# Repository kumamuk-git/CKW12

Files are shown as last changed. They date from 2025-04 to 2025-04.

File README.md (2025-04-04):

# CKW12
CKW12はクリックあり1U水平ロータリエンコーダです  
+ EC12に極力寄せたフットプリント
+ 通常プロファイル、ロープロファイルいずれの高さにも調整可能

## Whare to Buy

[BOOTH](https://kumamuk.booth.pm/items/6771437)にて組み立てキットが購入可能

## Build Guide

ビルドガイドは[こちら](https://github.com/kumamuk-git/CKW12/blob/main/doc/buildguide.md)

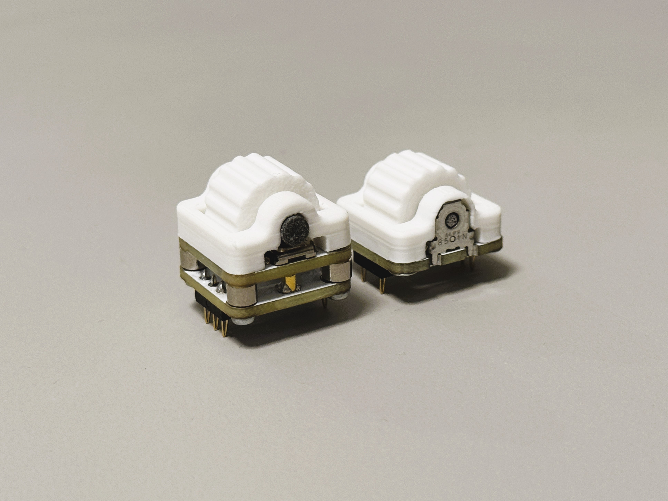
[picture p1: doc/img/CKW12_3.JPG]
  
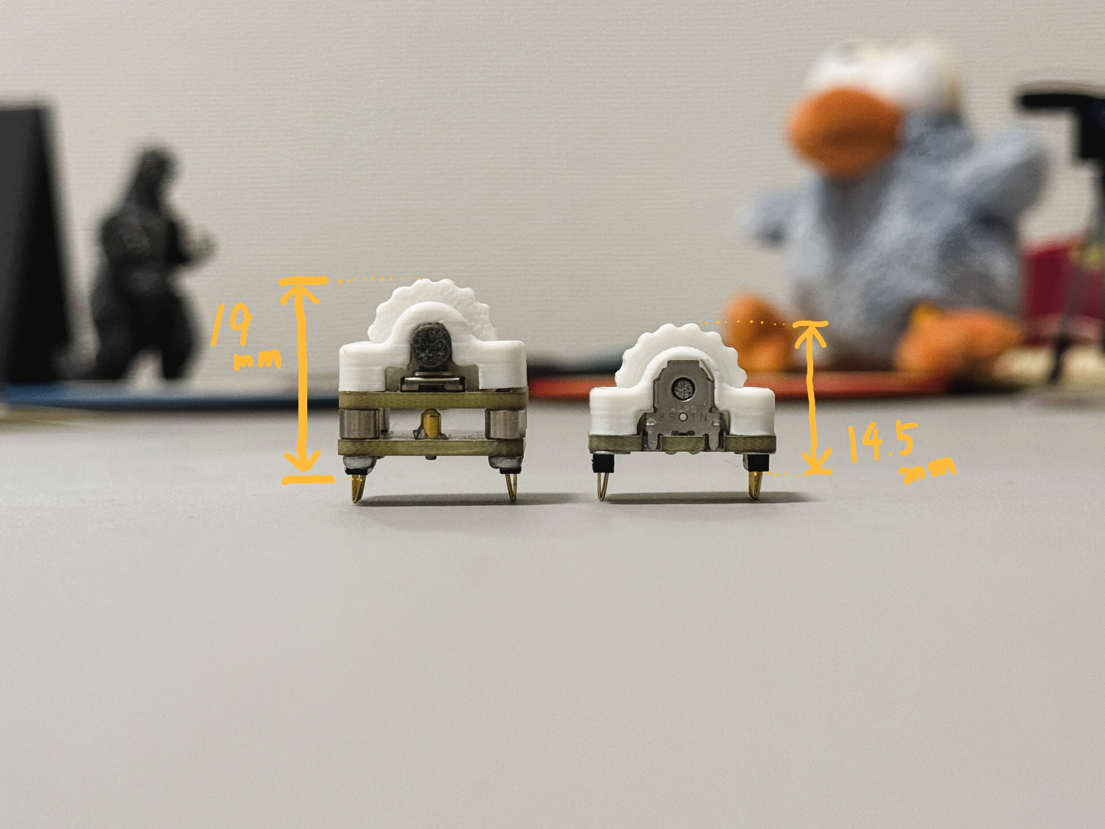
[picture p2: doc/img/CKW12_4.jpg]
  
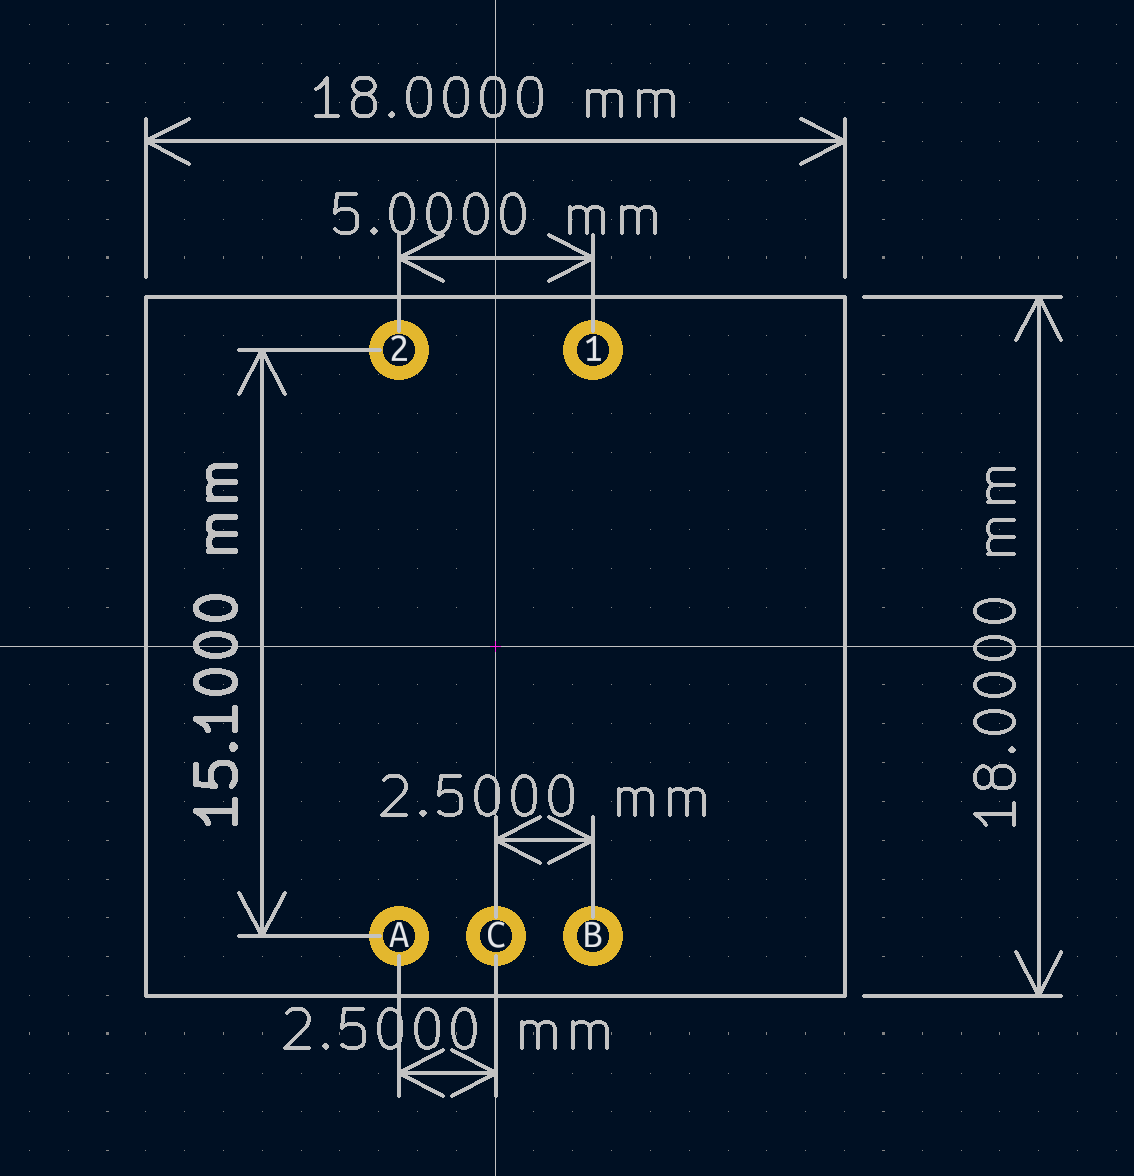
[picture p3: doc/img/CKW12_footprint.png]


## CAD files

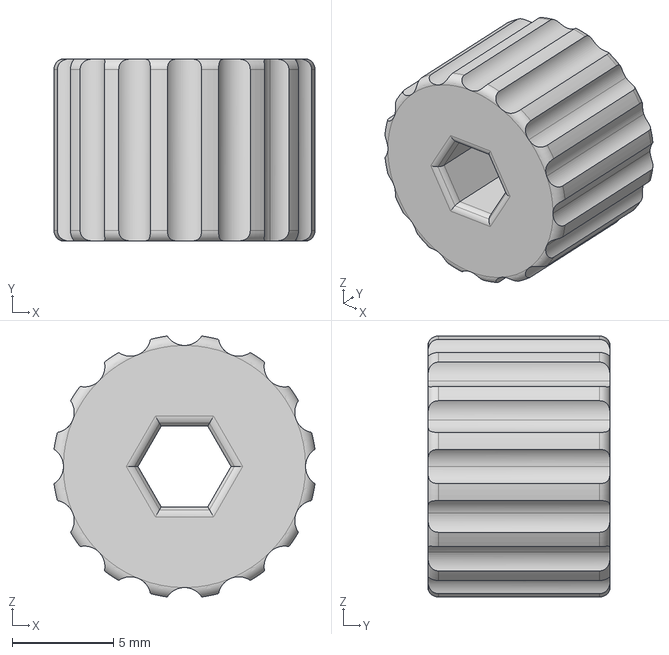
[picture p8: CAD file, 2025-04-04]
3dmodel/ckw12_wheel.stp
12.9 x 9.00 x 12.9 mm

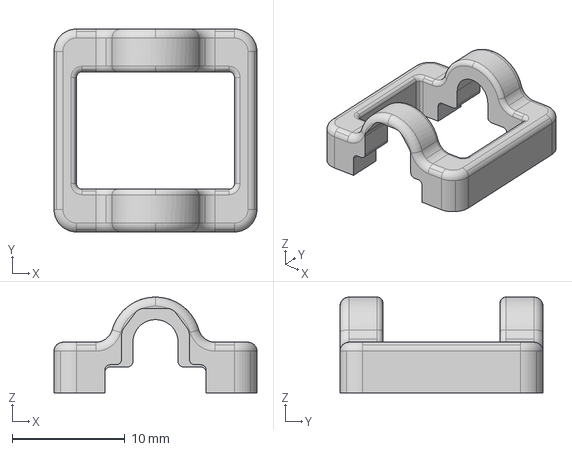
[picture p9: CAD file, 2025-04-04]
3dmodel/ckw12_housing.stp
18.0 x 18.0 x 8.50 mm

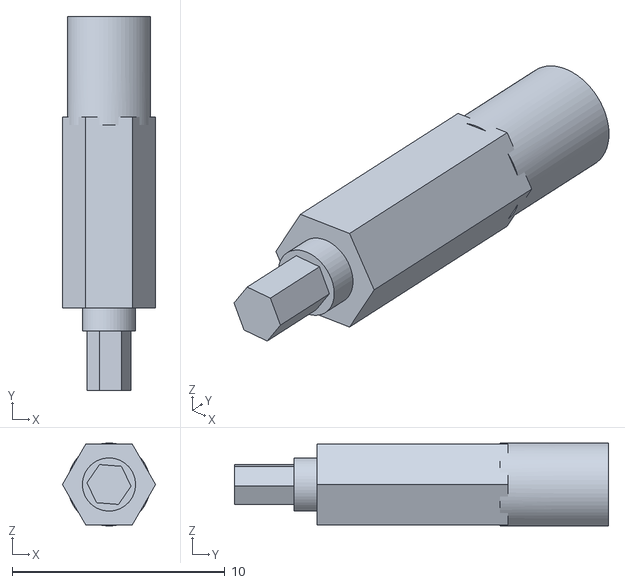
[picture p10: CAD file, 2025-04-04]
3dmodel/ckw12_stem.stl
4.39 x 17.6 x 3.90

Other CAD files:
3dmodel/ckw12_stem_for_nylon.stl

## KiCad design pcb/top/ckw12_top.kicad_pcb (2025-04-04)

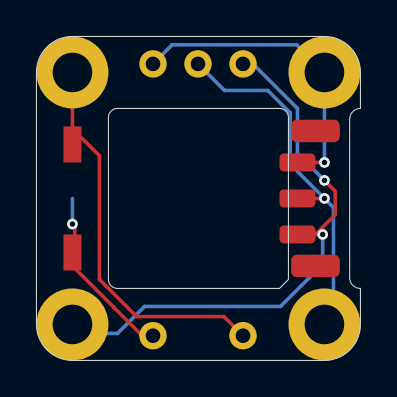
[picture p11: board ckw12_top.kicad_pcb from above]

Board: 2 copper layers, 18.0 x 18.0 mm, 8 parts (1 on the bottom side), 5 nets.

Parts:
J1, J2, J3, J4: Conn_01x01_Pin; my_mount_hole_M2_pad
J5: Conn_01x01_Pin; TestPoint_Pad_D2.0mm
SW1: RotaryEncoder; EC05E1220202
SW2: SW_DPST_x2; SKQYACE010
SW21: CKW12

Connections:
unnamed: SW1.B, SW21.B
unnamed: SW1.C, SW21.C
unnamed: SW1.A, SW21.A
unnamed: SW2.2 (B), SW21.2
unnamed: J5.1, SW2.1 (A), SW21.1

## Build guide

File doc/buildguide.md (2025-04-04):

# CKW12の組み立て  

LP版では一部部品が不要です。

## 必要部品
| 名前 | 数 | 備考 |
|:-|---:|:-|
| ハウジング | 1個 ||
| ホイール | 1個 | 3Dプリント品|
| ステム | 1個 | 3Dプリント品|
| EC05E1220202 | 1個 | |
| コンスルーピン(3ピン) | 2個 |うち1つは中央のピンが不必要のため取り外しています |
| CKW12_top基板 | 1枚 | |
| ネジ M2 3.5mm or 8mm | 4本 |  LP版...3.5mm 通常版...8mm　|
| CKW12_bottom基板 | 1枚 |LP版では不要|
| スペーサー M2 3mm | 4本 |LP版では不要 |
| スプリングピン(ポゴピン) | 1本 | LP版では不要|

## 組み立て手順

### 目次
  - [1. top基板（共通）](#1-上部基板共通)
    - [1-1. コンスルー取付（LP版のみ）](#1-1-コンスルー取付lp版のみ)
  - [2. bottom基板（LP版不要）](#2-bottom基板lp版不要)

### 1. top基板（共通）

写真のようにtop基板にロータリーエンコーダ(EC05E1220202 )を置き、はんだで固定します。  
エンコーダ側面からはんだ付けすると楽かと思います。  
***端子部分ははんだ不良が起きやすいので、端子を小手でパッド側に押し付けつつ温めてはんだを流し込むようにすると良さそうです。***  
なのでここも細かい小手先がいいですね。  
エンコーダが動かない場合の原因は十中八九これです。  
きれいにはんだ出来ているように見えてもここを疑ってください。

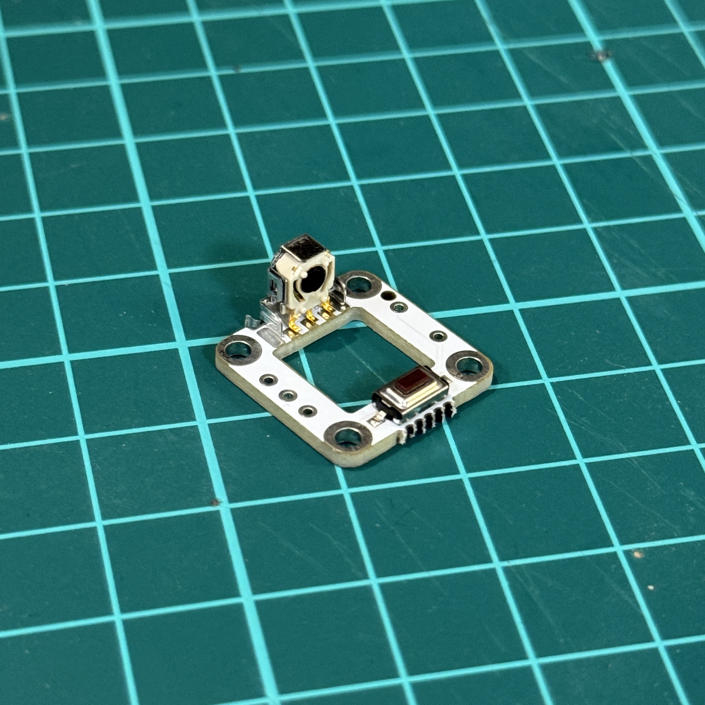
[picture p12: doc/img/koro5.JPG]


エンコーダにホイールとステムを取り付けます。  
まず、ホイールを置き、そしてスイッチ側からホイールの穴を通す形でステムを入れ込み、
ステムの先端をロータリーエンコーダに差し込んでください。  
ここで無理に押し込むとステムが折れてしまいます。  
***ステムの先端と、エンコーダーの穴がそれぞれ六角形になっているので、向きが合うのを確認してから慎重に差し込んでください。***

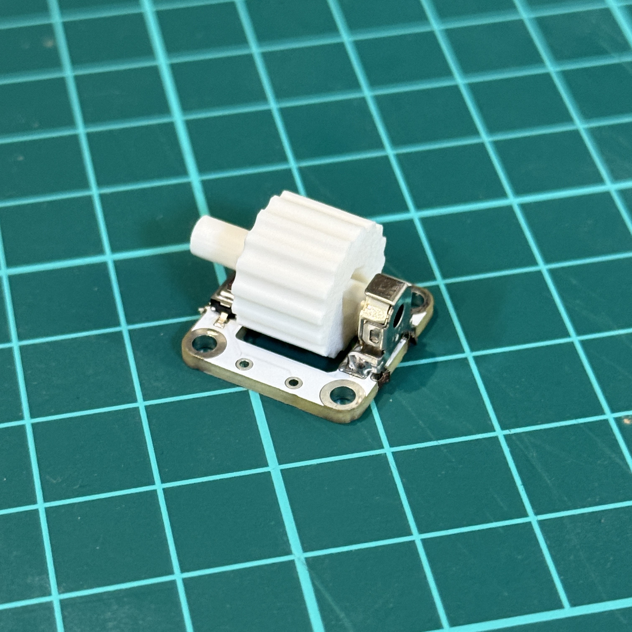
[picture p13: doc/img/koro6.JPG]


そして上からハウジングをかぶせます。
ハウジングの細かいサポート材が取り切れていないときれいに嵌らない場合があるので、もし取り残しがあればピンセットなどで取り除いてください。  

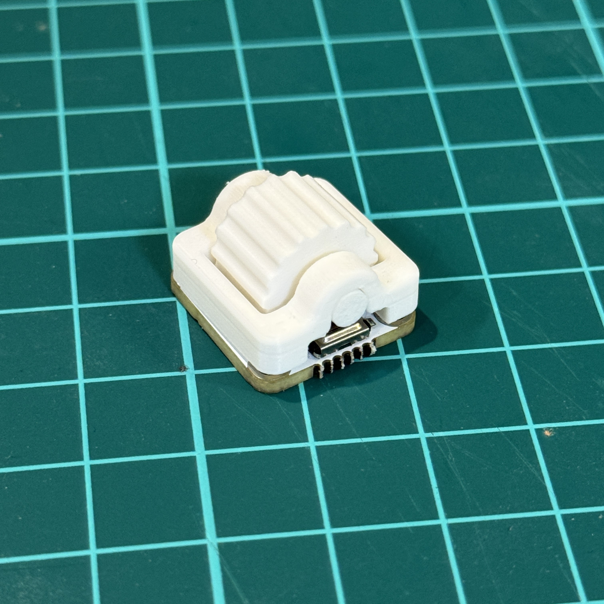
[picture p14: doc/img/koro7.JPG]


#### 1-1. コンスルー取付（LP版のみ）

LP版の場合はこの時点でコンスルーを取り付けてください。  
ハウジングかぶせてからでも可。  
※デカ指失礼
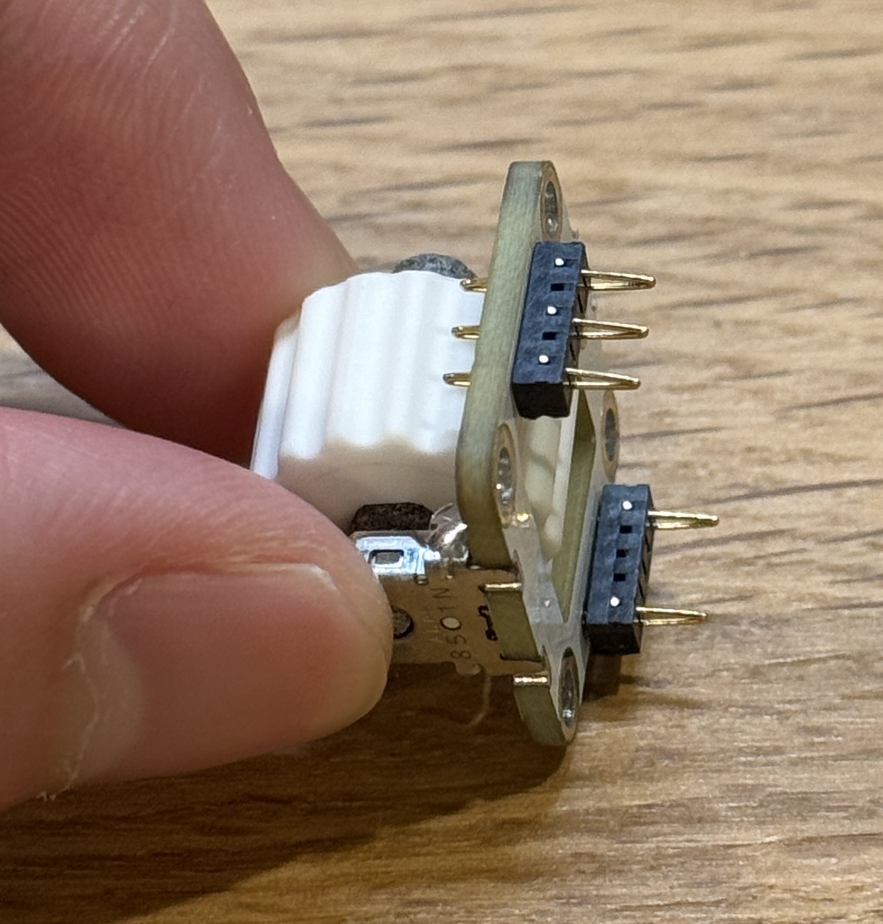
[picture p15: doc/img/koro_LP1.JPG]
  

そしてM2ネジ3.5mmでハウジングを固定してください。  
※デカ指失礼2  
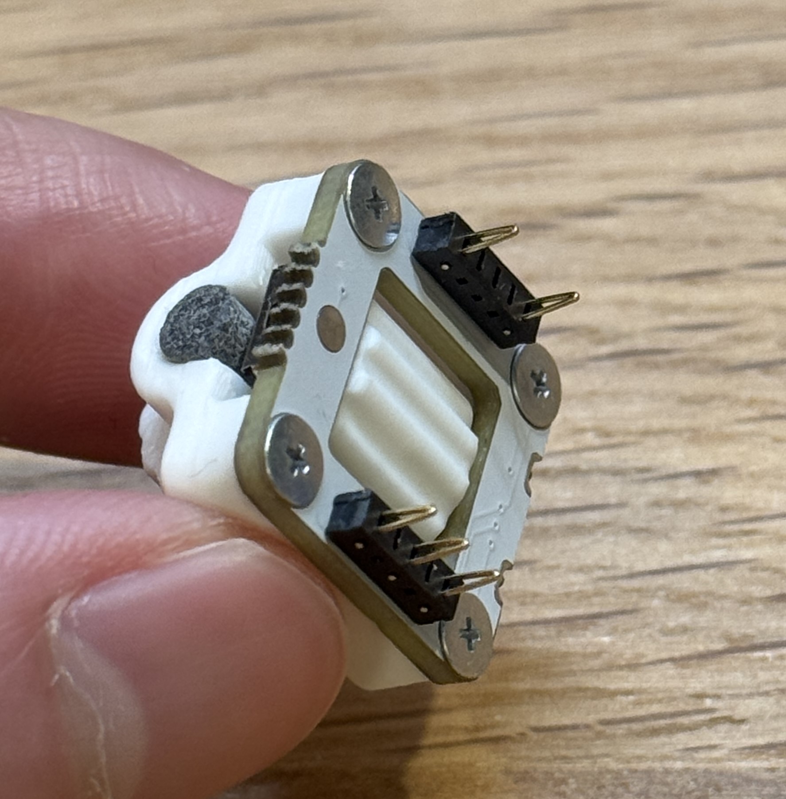
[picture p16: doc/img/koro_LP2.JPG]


LP版は異常で組み立て完了です。  

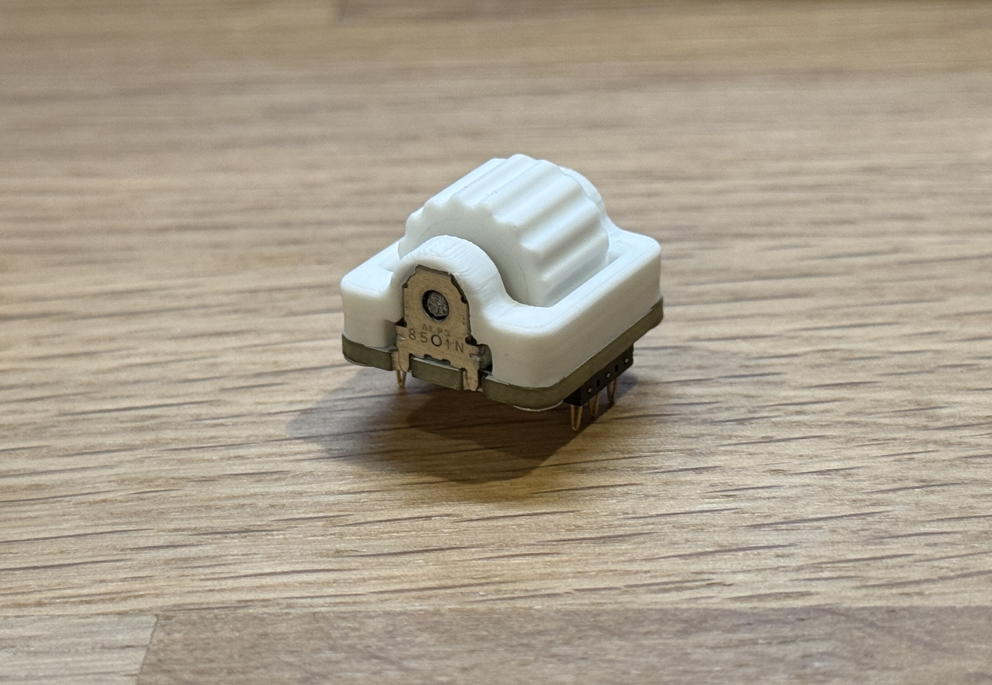
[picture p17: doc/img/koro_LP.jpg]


### 2. bottom基板（LP版不要）

bottom基板（中央に穴のないほう）にポゴピンを1本付けます。  
分かりづらいですが、切り離す前に部品がついていたほうが表になります。  
表面に対して、上からポゴピンを差し込みます。
マステ等で固定して、裏からはんだ付けがいいかな思います。  

***↓これが表面です。***
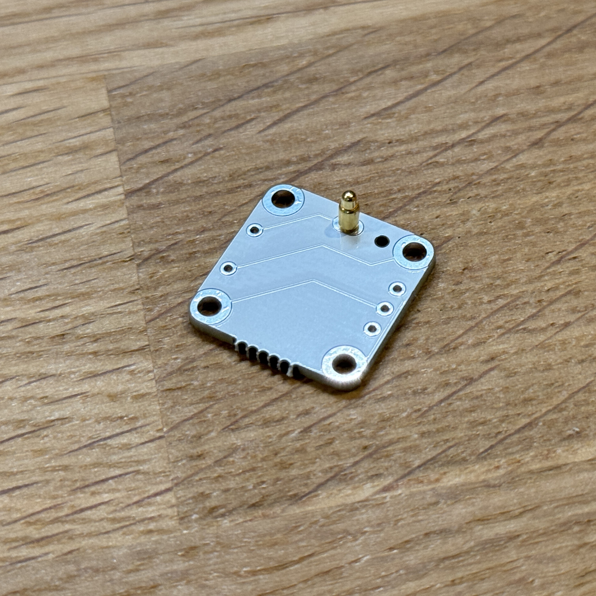
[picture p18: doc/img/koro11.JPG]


続いて裏面から8mmのネジで3mmスペーサーを固定します。  
このスペーサーが上下基板を繋ぐ導体になります。
そして写真のようにコンスルーを取り付けます。  

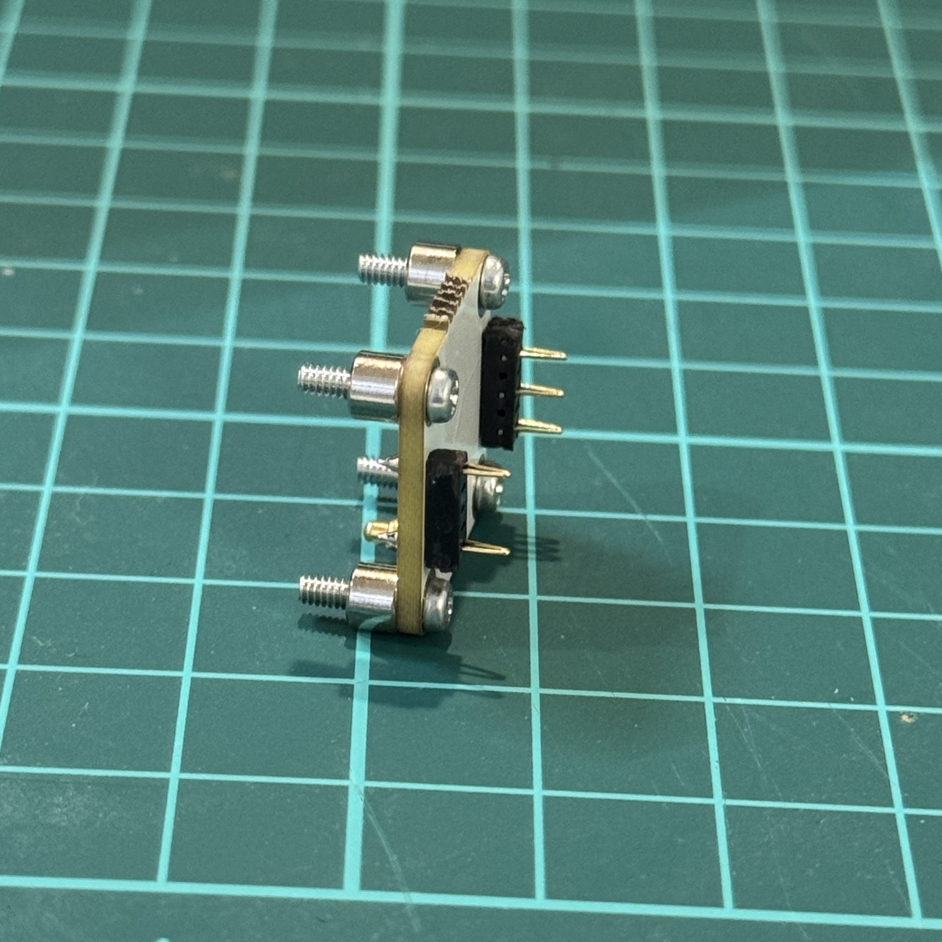
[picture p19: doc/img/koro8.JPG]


上下を取り付けます。
タクトスイッチ裏のパッドにポゴピンが当たるような向きにして、ネジをハウジングに差し込み固定してください。  
この際に固定が緩いと上下の基板の接続不良となってしまうため、しっかりと固定してください。

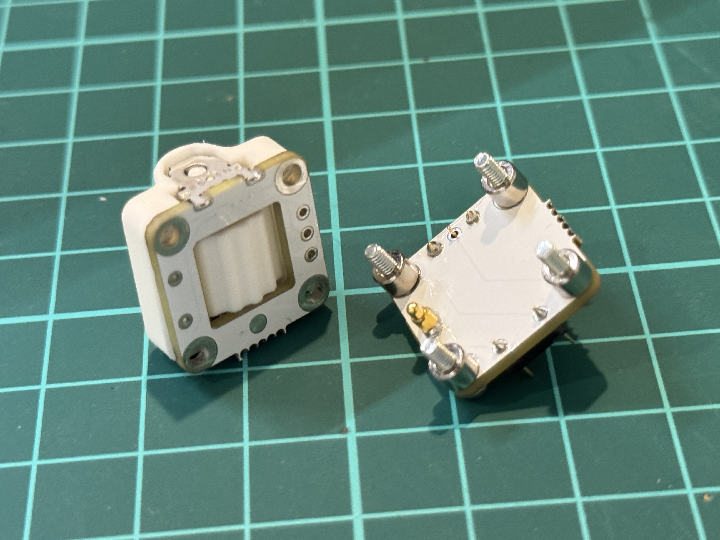
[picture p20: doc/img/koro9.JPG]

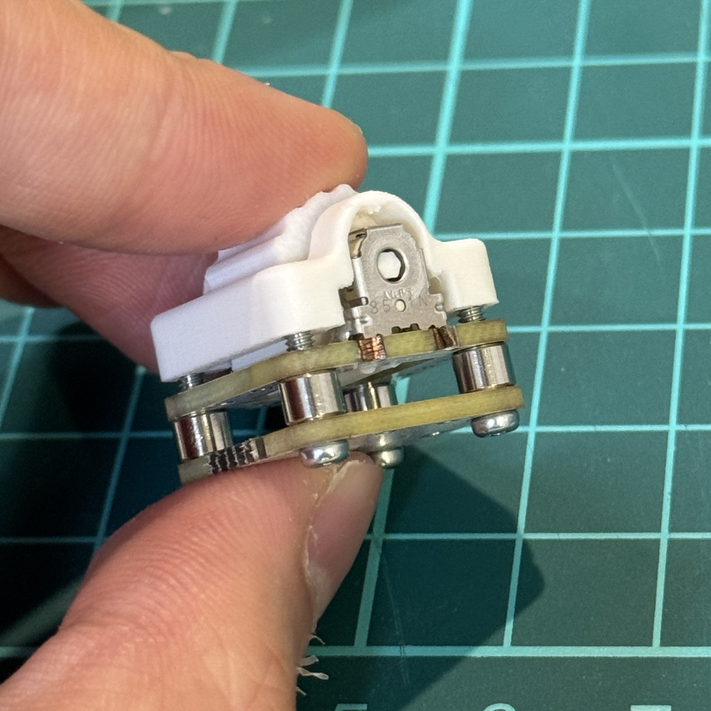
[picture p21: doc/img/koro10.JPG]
  
↑隙間がなくなるまでネジを締めてください。

以上で組み立て完了です。  
コンスルーを基板に差し込み取り付けてください。
なお、コンスルーの差し込みのみでの固定なので若干ぐらつきがあります。  
気になる場合は交換不可になりますが、基板にはんだで固定してしまってもよいかもしれません。

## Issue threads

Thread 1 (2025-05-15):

ライセンス

yudai-nkt, 2025-05-15:
このリポジトリで公開されているデータを用いてJLCに製造を発注したいのですが，使用にあたってのライセンスをご教示いただけないでしょうか？

yudai-nkt, 2025-05-15:
回答ありがとうございます，非商用・私的利用の範囲内に留めますので使わせていただきます．派生物の公開予定なども特にありません．

私の用途としては解決しましたが，ライセンスを定めるまでこのissueを開けておくかはお任せいたします．

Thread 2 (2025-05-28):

EC05E1220202 mounted the wrong way

jfaixo, 2025-05-28:
First of all, nice design and idea !

Just something I noticed while looking at the specs of the Alps EC05E1220202: the shaft insertion is supposed to be in the opposite way in the documentation. I suppose that's not a big deal, but wanted to report that, just in case.

Keep up the good work !

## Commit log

2025-04-04 add CKW12
    [ckw12_bottom.kicad_pcb, ckw12_bottom.kicad_sch, ckw12_housing.stp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]
2025-11-08 改良版ホイールの追加
